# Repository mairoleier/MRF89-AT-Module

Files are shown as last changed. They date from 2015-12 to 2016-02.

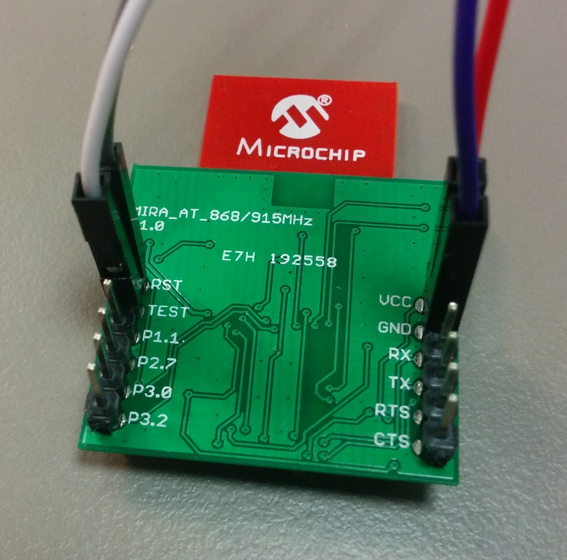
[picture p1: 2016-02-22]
images/MRF_AT_bot.jpg

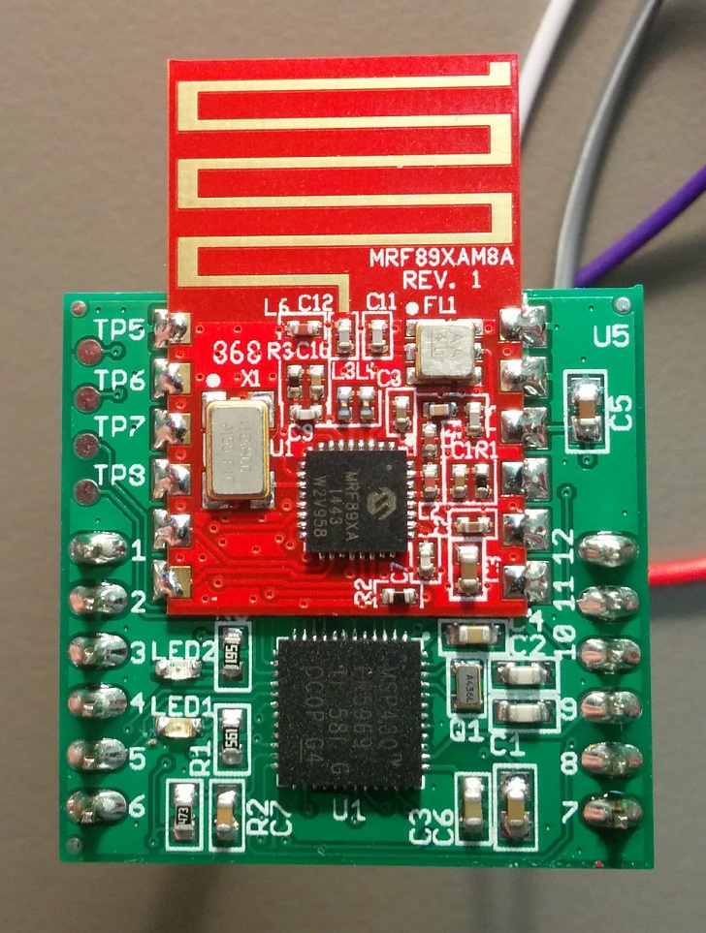
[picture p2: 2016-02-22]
images/MRF_AT_top.jpg

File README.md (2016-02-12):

# MRF_AT_868/915_v1.0

This is  the first version of MRF89XA 868MHz RF module that could be controlled with AT commands. 
It has integrated MSP430FR5969 module that takes care of the control of the RF module. It stays in low power mode if there is
no data to handle.

Module web page: http://mairoleier.github.io/MRF89-AT-Module

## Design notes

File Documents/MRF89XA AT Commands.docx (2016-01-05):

# MRF89 AT Commands

Version 1.0

Command | Response | Example
AT | OK | Test AT startup
AT+RST | OK | Restart module
AT+VER | OK AT:<AT version> SW:<SW version> | View version info
AT+UART=<speed> (not yet implemented) | OK | Set UART speed (9600, 115200)
AT+RFPOWER=<power> | OK Error: Unknown TX power mode | Set RF TX power (1-8) => -8…+13dBm 1: -8 dBm 2: -5 dBm 3: -2 dBm 4: +1 dBm 5: +4 dBm 6: +7 dBm 7: +10 dBm 8: +13 dBm
AT+RFCHANNEL=<rf_channel_no> | OK ERROR:03:Unknown radio channel | Set RF channel (1..21) 1: Channel 1 … 21: Channel 21
AT+RFDRATE=<rf_datarate> | OK | Set RF datarate 1: 2 kbps Range: +6 dBm 1: 10 kbps Range: -1 dBm 3: 33 kbps Range: -2 dBm 4: 100 kbps Range: -5.5 dBm
AT+RFMODE=<mode> | OK / ERROR (RX mode only): DATA: - <packet_length>, - <src_addr>, - <dst_addr>, - <encryption_flag>, - <rcv_signal_strength>, - <data> | Set RF module mode 1: RX 2: STANDBY 3: SLEEP Data received from remote address Default:
AT+LADDR=<addr> | OK ERROR: Unknown address | Set local node address (addr: 1..255) If out of allowed range then error
AT+NADDR=<addr1:addr2:addr3:addr4> | OK | Set network address <4 bytes> (A:B:C:D)
AT+RFSEND=<dest_addr>,<encryption>,<ACK>,<data> | OK ERROR:<error_code> | Send data to destination address. Data packet can be up to 60 bytes. If ACK is on then wait for ack Set RF communication encryption (0: OFF / 1: ON)
AT+ENCKEY=<enc_key> (not yet implemented) | OK | Set AES-128 encryption key, in comma separated form

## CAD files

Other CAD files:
Software/FW_MSP430FR5969_MRF89XA/Debug/AT/commands.obj
Software/FW_MSP430FR5969_MRF89XA/Debug/driverlib/MSP430FR5xx_6xx/timer_a.obj
Software/FW_MSP430FR5969_MRF89XA/Debug/HAL/spi.obj
Software/FW_MSP430FR5969_MRF89XA/Debug/Radio/drivers/rf_time.obj
Software/FW_MSP430FR5969_MRF89XA/Debug/Radio/LNK/radio.obj
Software/FW_MSP430FR5969_MRF89XA/Debug/Radio/NWK/aes.obj
Software/FW_MSP430FR5969_MRF89XA/Debug/driverlib/MSP430FR5xx_6xx/ref_a.obj
Software/FW_MSP430FR5969_MRF89XA/Debug/HAL/uart.obj
Software/FW_MSP430FR5969_MRF89XA/Debug/Radio/drivers/rf_spi.obj
Software/FW_MSP430FR5969_MRF89XA/Debug/Radio/NWK/nwk_security.obj
Software/FW_MSP430FR5969_MRF89XA/Debug/driverlib/MSP430FR5xx_6xx/ram.obj
Software/FW_MSP430FR5969_MRF89XA/Debug/HAL/gpio.obj
Software/FW_MSP430FR5969_MRF89XA/Debug/Radio/NWK/nwk_radio.obj
Software/FW_MSP430FR5969_MRF89XA/Debug/driverlib/MSP430FR5xx_6xx/eusci_a_spi.obj
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

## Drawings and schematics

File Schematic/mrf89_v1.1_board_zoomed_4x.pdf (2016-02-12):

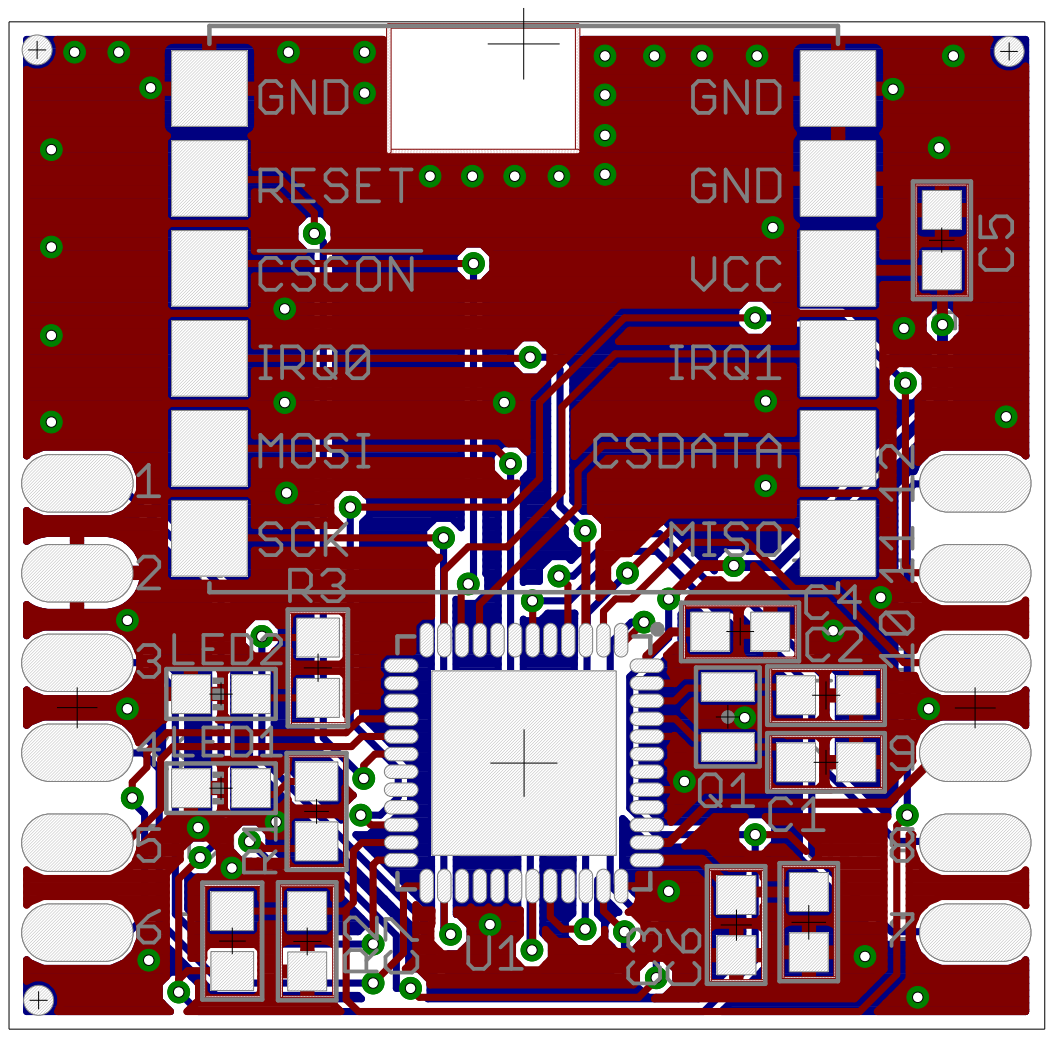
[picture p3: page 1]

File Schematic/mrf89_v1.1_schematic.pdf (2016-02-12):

A

A

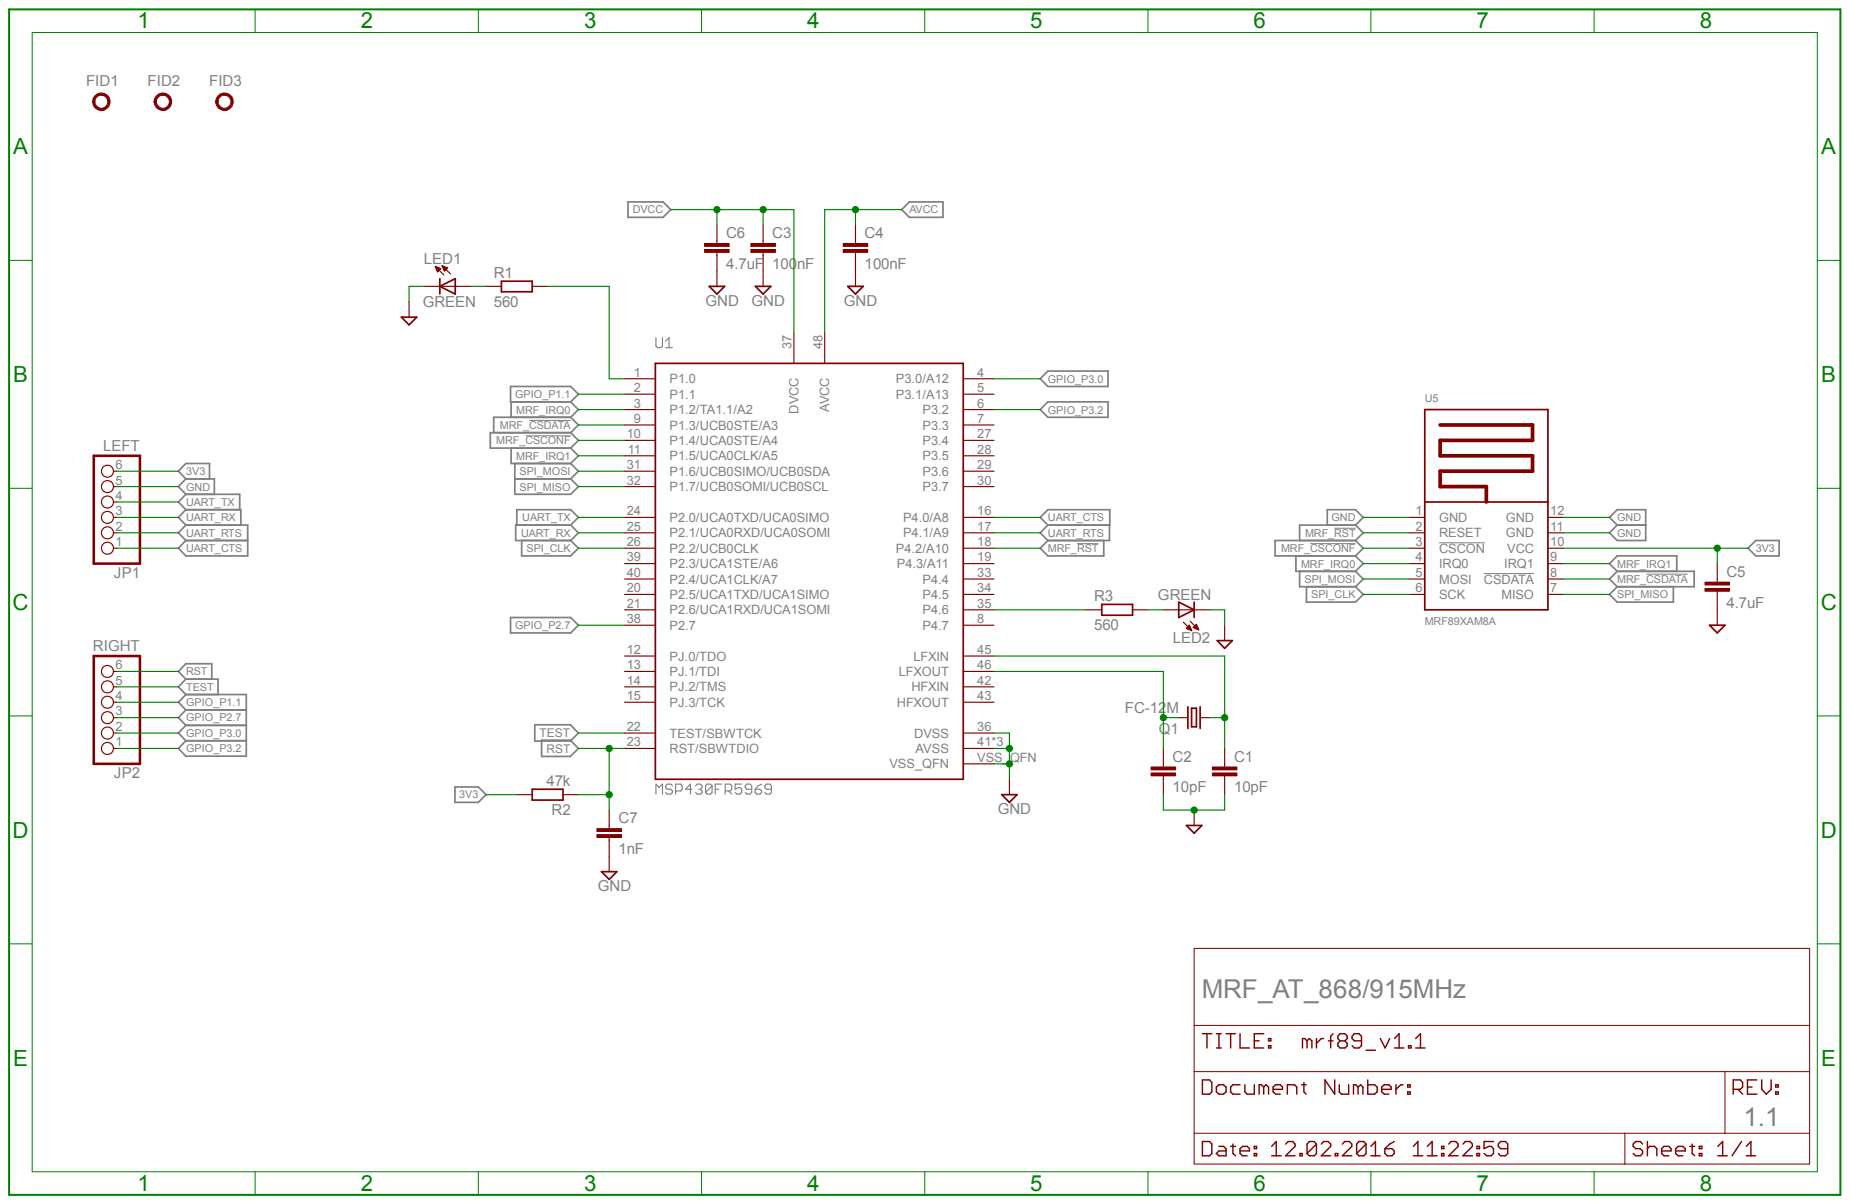
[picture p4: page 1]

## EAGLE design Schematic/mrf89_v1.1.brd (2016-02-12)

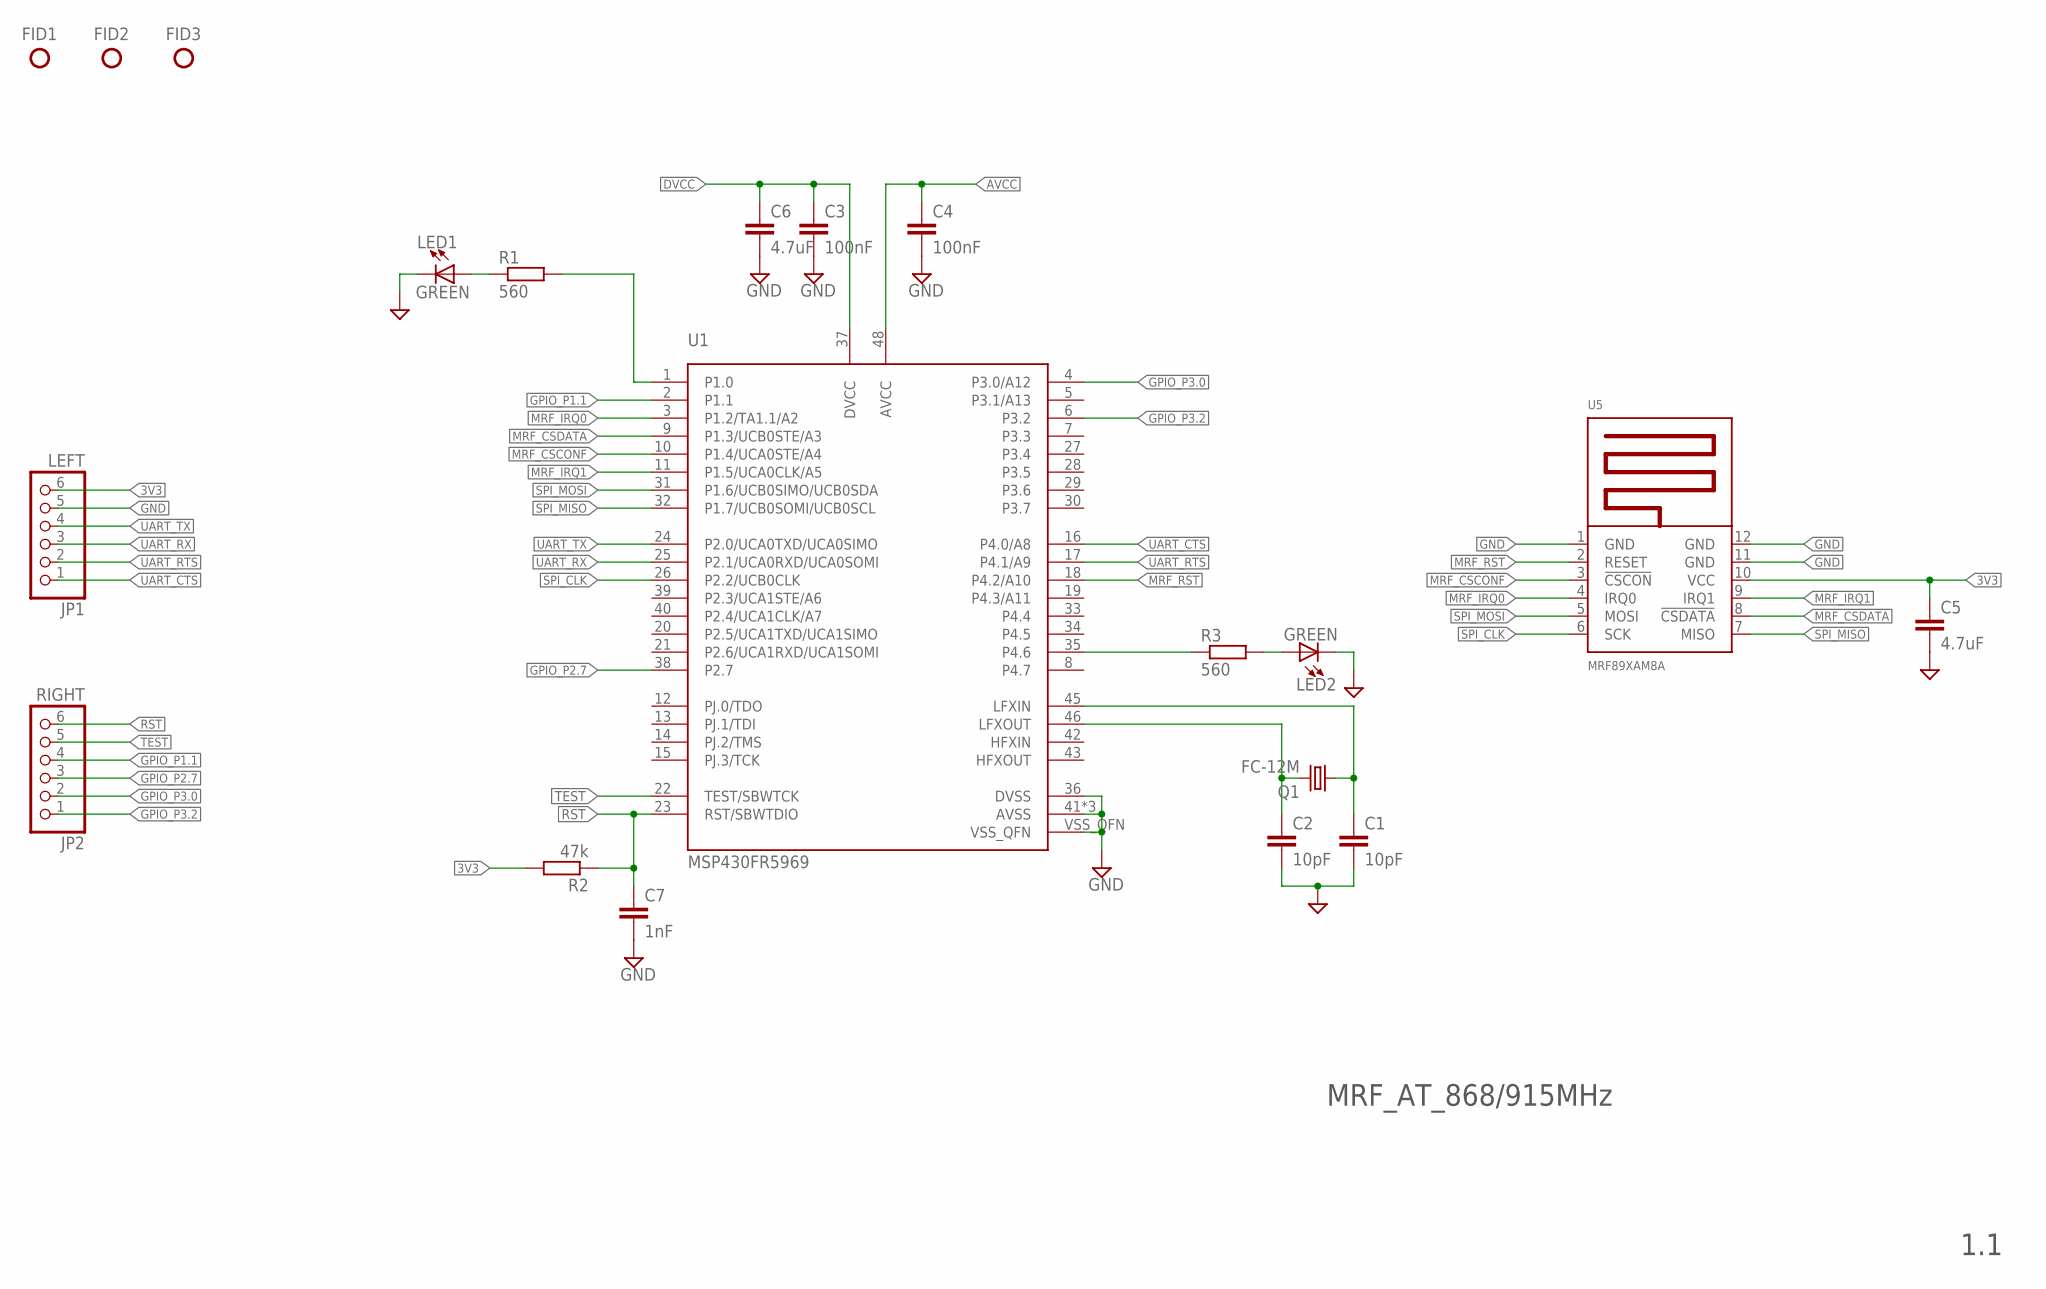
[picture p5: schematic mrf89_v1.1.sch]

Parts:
C1, C2: 10pF; C0603
C3, C4: 100nF; C0603
C5, C6: 4.7uF; C0603
C7: 1nF; C0603
FID1, FID2, FID3: FIDUCIAL
JP1: LEFT; 1X06
JP2: RIGHT; 1X06
LED1, LED2: GREEN; CHIP-LED0603
Q1: FC-12M
R1, R3: 560; R0603
R2: 47k; R0603
U1: MSP430FR5969; S-PVQFN-N48
U5: MRF89XAM8A; MRF89XAMXA

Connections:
3V3: C5.1, JP1.6, R2.2, U5.10 (VCC)
AVCC: C4.1, U1.48 (AVCC)
DVCC: C3.1, C6.1, U1.37 (DVCC)
GND: C1.2, C2.2, C3.2, C4.2, C5.2, C6.2, C7.2, JP1.5, LED1.C, LED2.C, U1.36 (DVSS), U1.41 (AVSS), U1.44 (AVSS), U1.47 (AVSS), U1.VSS_QFN, U5.1 (GND), U5.11 (GND), U5.12 (GND)
GPIO_P1.1: JP2.4, U1.2 (P1.1)
GPIO_P2.7: JP2.3, U1.38 (P2.7)
GPIO_P3.0: JP2.2, U1.4 (P3.0/A12)
GPIO_P3.2: JP2.1, U1.6 (P3.2)
LFXIN: C1.1, Q1.1, U1.45 (LFXIN)
LFXOUT: C2.1, Q1.2, U1.46 (LFXOUT)
MRF_!CSCONF: U1.10 (P1.4/UCA0STE/A4), U5.3 (!CSCON)
MRF_!CSDATA: U1.9 (P1.3/UCB0STE/A3), U5.8 (!CSDATA)
MRF_!RST: U1.18 (P4.2/A10), U5.2 (RESET)
MRF_IRQ0: U1.3 (P1.2/TA1.1/A2), U5.4 (IRQ0)
MRF_IRQ1: U1.11 (P1.5/UCA0CLK/A5), U5.9 (IRQ1)
unnamed: LED2.A, R3.2
unnamed: LED1.A, R1.1
P1.0: R1.2, U1.1 (P1.0)
P4.6: R3.1, U1.35 (P4.6)
RST: C7.1, JP2.6, R2.1, U1.23 (RST/SBWTDIO)
SPI_CLK: U1.26 (P2.2/UCB0CLK), U5.6 (SCK)
SPI_MISO: U1.32 (P1.7/UCB0SOMI/UCB0SCL), U5.7 (MISO)
SPI_MOSI: U1.31 (P1.6/UCB0SIMO/UCB0SDA), U5.5 (MOSI)
TEST: JP2.5, U1.22 (TEST/SBWTCK)
UART_CTS: JP1.1, U1.16 (P4.0/A8)
UART_RTS: JP1.2, U1.17 (P4.1/A9)
UART_RX: JP1.3, U1.25 (P2.1/UCA0RXD/UCA0SOMI)
UART_TX: JP1.4, U1.24 (P2.0/UCA0TXD/UCA0SIMO)

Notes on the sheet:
MRF_AT_868/915MHz
1.1

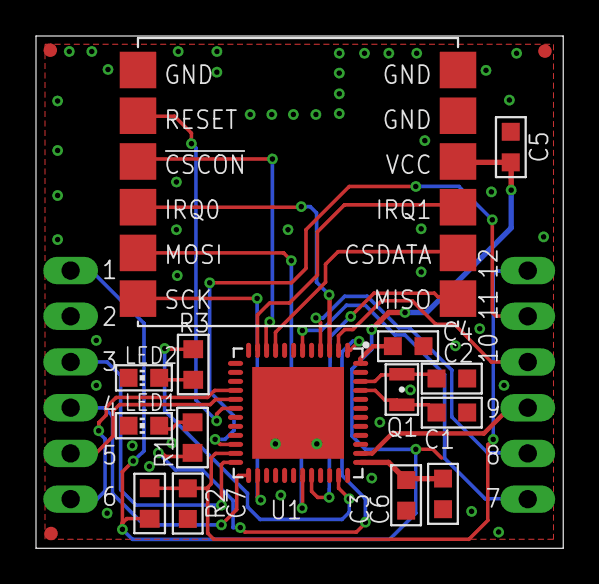
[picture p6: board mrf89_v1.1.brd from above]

Board: 2 copper layers, 29.3 x 28.5 mm, 20 parts (0 on the bottom side), 28 nets.

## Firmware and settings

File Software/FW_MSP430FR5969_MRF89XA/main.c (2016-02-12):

/*
 * main.h
 *
 *  Author: Mairo Leier, Maksim Gorev
 *
 *	Version: 0.4		12.02.2016
 *	Fix: main.c		MSP goes into LPM1, not anymore LPM3 because UART may skip sometimes first chars
 *
 *  Version: 0.3		15.10.2015
 *  Fix: radio.c:	Radio_Set_Mode()		If radio is set to Rx then it is initialized again because if it
 *  										has been previously in sleep mode then all configuration is lost
 *
 */
/***************************************************************************************************
 *	        Include section					                       		   					       *
 ***************************************************************************************************/

// System
#include "HAL/include/system.h"
#include "HAL/include/uart.h"
#include "HAL/include/spi.h"

// RF LNK Layer
#include "Radio/LNK/radio.h"

// RF Network Layer
#include "Radio/NWK/nwk_security.h"
#include "Radio/NWK/nwk_radio.h"

// AT specific commands
#include "AT/commands.h"
/***************************************************************************************************
 *	        Define section					                       		   					       *
 ***************************************************************************************************/


/***************************************************************************************************
 *	        Prototype section					                       							   *
 ***************************************************************************************************/



/***************************************************************************************************
 *	        Global Variable section  				                            				   *
 ***************************************************************************************************/
uint8_t exit_code = 0;		// Exit code number that is set after function exits


/***************************************************************************************************
 *         Main section                                                                            *
 ***************************************************************************************************/
void main(void) {

	// Initialize default RF settings
	rf_data.local_addr 	 	= DEF_LOCAL_ADDR;
	rf_data.network_addr[0] = DEF_NETWORK_ADDR1;
	rf_data.network_addr[1] = DEF_NETWORK_ADDR2;
	rf_data.network_addr[2] = DEF_NETWORK_ADDR3;
	rf_data.network_addr[3] = DEF_NETWORK_ADDR4;
	rf_data.tx_power 		= DEF_TX_POWER;
	rf_data.channel_no		= DEF_RF_CHANNEL;
	rf_data.data_rate		= DEF_RF_DATA_RATE;

	// Initialize system
	exit_code = System_Init();
	if (exit_code)
		Print_Error(exit_code);

	UART_Send_Data("\r\nMRF89XA Wireless Module\r\n");
	UART_Send_Data("Version 0.1\r\n");


	while (1)
	{
		exit_code = 0;

		if (data_rcv_flag) {
			data_rcv_flag = 0;

			if (Check_Uart_Answer(CMD_AT) == 0)
			{
				UART_Send_Data(ANSW_OK);
			}
			else if (Check_Uart_Answer(CMD_AT_RST) == 0)
			{
				UART_Send_Data(ANSW_OK);
				System_Reset();
			}
			else if (Check_Uart_Answer(CMD_AT_VER) == 0)
			{
				UART_Send_Data(ANSW_OK);
				UART_Send_Data("AT:0.1 SW:0.1\r\n");
			}
			else if (Check_Uart_Answer_Block(CMD_AT_RFSEND,10) == 0)
			{
				Send_Rf_Data();
			}
			else if (Check_Uart_Answer_Block(CMD_AT_RFMODE,10) == 0)
			{
				Set_Rf_Mode(uart_data[10]);
			}
			else if (Check_Uart_Answer_Block(CMD_AT_RFLADDR,9) == 0)
			{
				Set_Rf_Local_Address();
			}
			else if (Check_Uart_Answer_Block(CMD_AT_RFNADDR,9) == 0)
			{
				if (Set_Network_Address() == 1) {
					UART_Send_Data(ANSW_ERROR);
					UART_Send_Data("Unknown address\r\n");
				}
			}
			else if (Check_Uart_Answer_Block(CMD_AT_RFCHANNEL,12) == 0)
			{
				Set_Rf_Channel();
			}
			else if (Check_Uart_Answer_Block(CMD_AT_RFPOWER,11) == 0)
			{
				Set_Rf_Power();
			}
			else if (Check_Uart_Answer_Block(CMD_AT_RFDRATE,11) == 0)
			{
				Set_Rf_Data_Rate();
			}

			// Clear working buffers after each command
			Clear_Uart_Data_Buf();
			Clear_Work_Data_Buf();

		}	/* END: data_rcv_flag */

		// if rf module is in receive mode
		if (radio_mode_receive == 1) {
			Receive_Rf_Data();
		}

		// TODO: Use LPM3 together with UART RTS and CTS
		__bis_SR_register(LPM1_bits | GIE);       // Enter LPM3, interrupts enabled

	}	/* END: WHILE */
}		/* END: main */

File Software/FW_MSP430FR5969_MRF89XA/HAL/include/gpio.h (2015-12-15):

#ifndef DRIVERS_GPIO_H_
#define DRIVERS_GPIO_H_

/***************************************************************************************************
 *	        Include section					                       		   					       *
 ***************************************************************************************************/
#include <msp430.h>


/***************************************************************************************************
 *	        Define section					                       		   					       *
 ***************************************************************************************************/

/******** MRF89XA *********/
#define RF_IRQ_PORT_DIR		(P1DIR)
#define RF_IRQ_PORT_IN		(P1IN)
#define RF_IRQ_PORT_REN		(P1REN)
#define RF_IRQ_PORT_IE		(P1IE)
#define RF_IRQ_PORT_IES		(P1IES)
#define RF_IRQ_PORT_IFG		(P1IFG)

#define RF_IRQ0_PIN			BIT2	// P1.2
#define RF_IRQ1_PIN			BIT5	// P1.5

#define RF_RESET_PORT_DIR	(P4DIR)
#define RF_RESET_PORT_OUT	(P4OUT)
#define RF_RESET_PIN		BIT2	// P4.2


/********** LED ***********/
#define LED1_PORT_DIR      	(P1DIR)
#define LED1_PORT_OUT       (P1OUT)
#define LED1  	     		BIT0	// P1.0 (GREEN)

#define LED2_PORT_DIR      	(P4DIR)
#define LED2_PORT_OUT       (P4OUT)
#define LED2       			BIT6	// P4.6 (RED)



// IRQ definitions
#define RF_IRQ0_IN()  		{ RF_IRQ_PORT_DIR  &= ~RF_IRQ0_PIN; }
#define RF_IRQ1_IN()  		{ RF_IRQ_PORT_DIR  &= ~RF_IRQ1_PIN; }

// Enable interrupt
#define RF_IRQ0_IE()  		{ RF_IRQ_PORT_IE  |= RF_IRQ0_PIN; }
#define RF_IRQ1_IE()  		{ RF_IRQ_PORT_IE  |= RF_IRQ1_PIN; }

// Low to high edge
#define RF_IRQ0_IES()  		{ RF_IRQ_PORT_IES  &= ~RF_IRQ0_PIN; }
#define RF_IRQ1_IES()  		{ RF_IRQ_PORT_IES  &= ~RF_IRQ1_PIN; }

// Clear interrupt
#define RF_IRQ0_IFG()  		{ RF_IRQ_PORT_IFG  &= ~RF_IRQ0_PIN; }
#define RF_IRQ1_IFG()  		{ RF_IRQ_PORT_IFG  &= ~RF_IRQ1_PIN; }

// Pulldown resistor
#define RF_IRQ0_REN()  		{ RF_IRQ_PORT_REN  &= ~RF_IRQ0_PIN; }
#define RF_IRQ1_REN()  		{ RF_IRQ_PORT_REN  &= ~RF_IRQ1_PIN; }

// RF Module RESET pin
#define RF_RESET_OUT() 		{ RF_RESET_PORT_DIR |= RF_RESET_PIN; }
#define RF_RESET() 			{ RF_RESET_PORT_OUT |= RF_RESET_PIN; \
								__delay_cycles(20000); \
								RF_RESET_PORT_OUT &= ~RF_RESET_PIN;}
							// Keep RESET pin high for at least 100us


/***************************************************************************************************
 *	        Prototype section					                       							   *
 ***************************************************************************************************/


/***************************************************************************************************
 *	        Global Variable section  				                            				   *
 ***************************************************************************************************/

#endif 

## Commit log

2015-12-10 Initial schematic
    [mrf89_v0.1.sch]
2015-12-15 Schematic ready
    [mrf89_v0.1.brd, mrf89_v0.1.sch]
2015-12-15 Initial working version
    Most important AT commands are working with MSP430FR5969 Launchpad
    [adc12_b.obj, aes.obj, aes256.obj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]
2016-01-05 Finalized version 1.0
    Finalized version of schematic and PCB.
    Version 1.0
    [mrf89_v1.0.brd, mrf89_v1.0.sch]
2016-02-12 New board version 1.1 with bugs fixed in schematic. UART RX/TX pins were swapped. Better LED layout and 0805 caps were replaced with 0603. Software fix: MSP430 goes into LPM1. Previously LPM3 caused 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
    [adc12_b.obj, aes.obj, aes256.obj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]
